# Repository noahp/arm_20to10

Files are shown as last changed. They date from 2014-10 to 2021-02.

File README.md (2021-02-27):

arm_20to10
=====
20-pin to 10-pin ARM JTAG/SWD adapter, with toggle-able 3.3v LDO 
to power the target (jlink can output 5.0v on pin 19 of the arm 
20-pin connector).

pcb render
=====
front. . . . . .  back

assembly render
=====
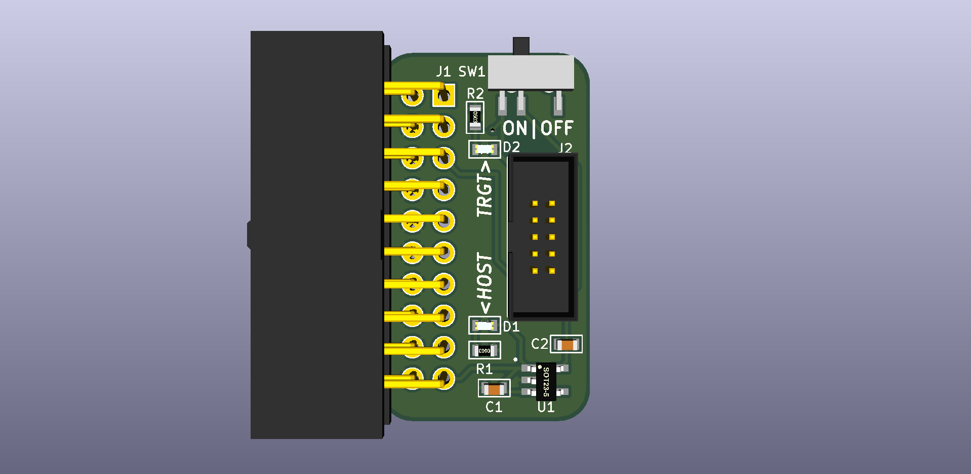
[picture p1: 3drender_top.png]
top

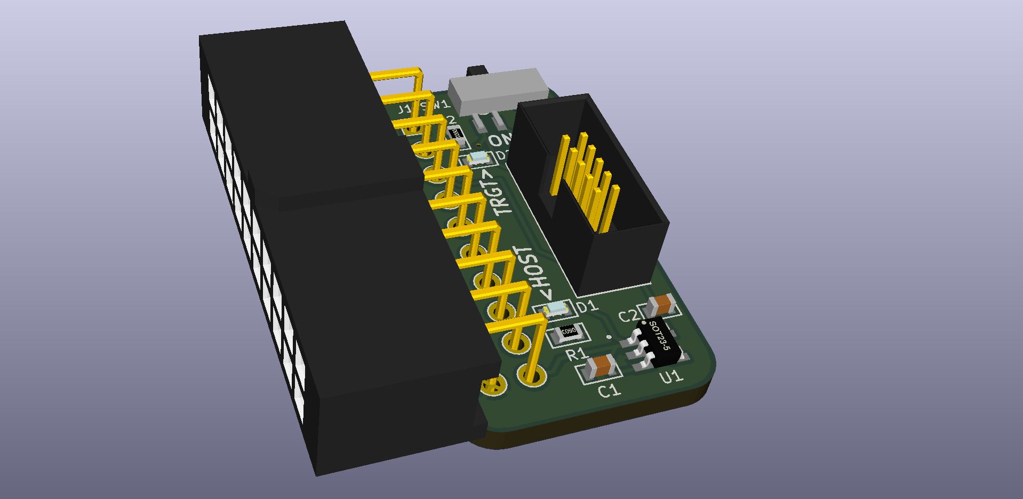
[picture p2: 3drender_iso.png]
iso


assembled unit
=====
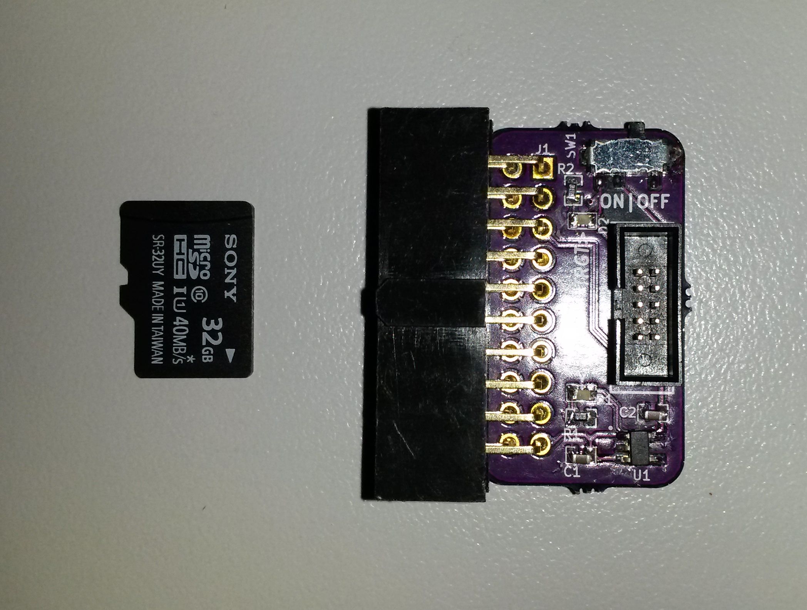
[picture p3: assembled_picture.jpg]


parts
=====
10 pin through hole male connector
-----
[digikey](http://www.digikey.com/product-detail/en/20021111-00010T4LF/609-3712-ND/2209072)  
[mouser](http://www.mouser.com/ProductDetail/FCI/20021111-00010T4LF/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)  
[ebay](http://www.ebay.com/itm/12-pcs-Gold-Plated-1-27mm-2x40-80pin-Breakable-Pin-Header-Male-Double-Row-Strip-/370935487630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)  
  
[shrouded, digikey](http://www.digikey.com/product-detail/en/3220-10-0100-00/1175-1627-ND/3883661)  

20 pin through hole female connector
-----
[digikey](http://www.digikey.com/product-detail/en/SFH11-PBPC-D10-ST-BK/S9197-ND/1990090)  
[ebay](http://www.ebay.com/itm/20-Pcs-2x10-Double-Row-20-Pins-PCB-Female-Header-2-54mm-/400316132430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)  
[digkey right angle](http://www.digikey.com/product-detail/en/SFH11-PBPC-D10-RA-BK/S9205-ND/1990098)  

3.3v ldo
-----
[mouser- skyworks sot23-5](http://www.mouser.com/ProductDetail/Skyworks-Solutions-Inc/AAT3223IGU-33-T1/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)  
[mouser- TI sot23-5](http://www.mouser.com/ProductDetail/Texas-Instruments/LP5907MFX-33-NOPB/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)  
[digikey- TI sot23-5](http://www.digikey.com/product-detail/en/TLV70233DBVR/296-32415-1-ND/3505572)  
[digikey- Micrel sot23-5 300mA](http://www.digikey.com/product-detail/en/MIC5504-3.3YM5%20TR/576-4764-1-ND/4864028)  

beefier ldo
----
[mouser- ON](http://www.mouser.com/ProductDetail/ON-Semiconductor/NCP1117LPST33T3G/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)  
[mouser- diodes](http://www.mouser.com/ProductDetail/Diodes-Incorporated/AP1117IE33G-13/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)  

slide switch
-----
[mouser- C&K](http://www.mouser.com/ProductDetail/CK-Components/PCM12SMTR/?qs=sGAEpiMZZMsqIr59i2oRcvc9UQrBbcoBkFYgnQFYwWU%3d)  
[digikey- Copal](http://www.digikey.com/product-detail/en/CUS-12TB/563-1102-1-ND/1124231)  
[mouser- ALPS](http://www.mouser.com/ProductDetail/ALPS/SSSS810701/?qs=sGAEpiMZZMtHXLepoqNyVe%252bcQMRoBF1BAzyvwoNmgBo%3d)

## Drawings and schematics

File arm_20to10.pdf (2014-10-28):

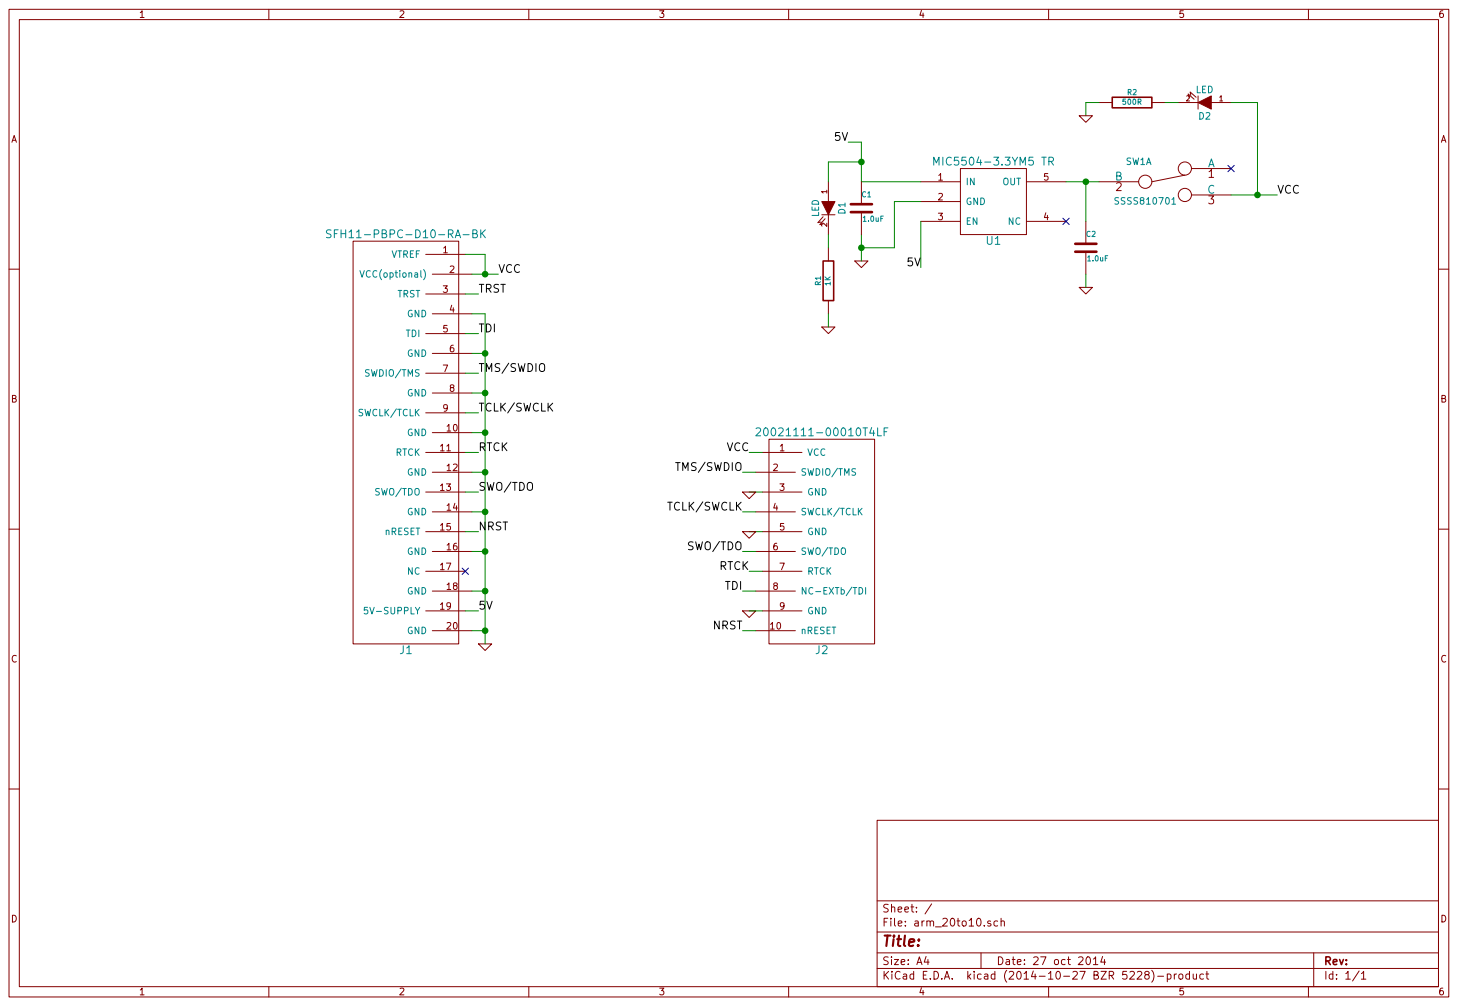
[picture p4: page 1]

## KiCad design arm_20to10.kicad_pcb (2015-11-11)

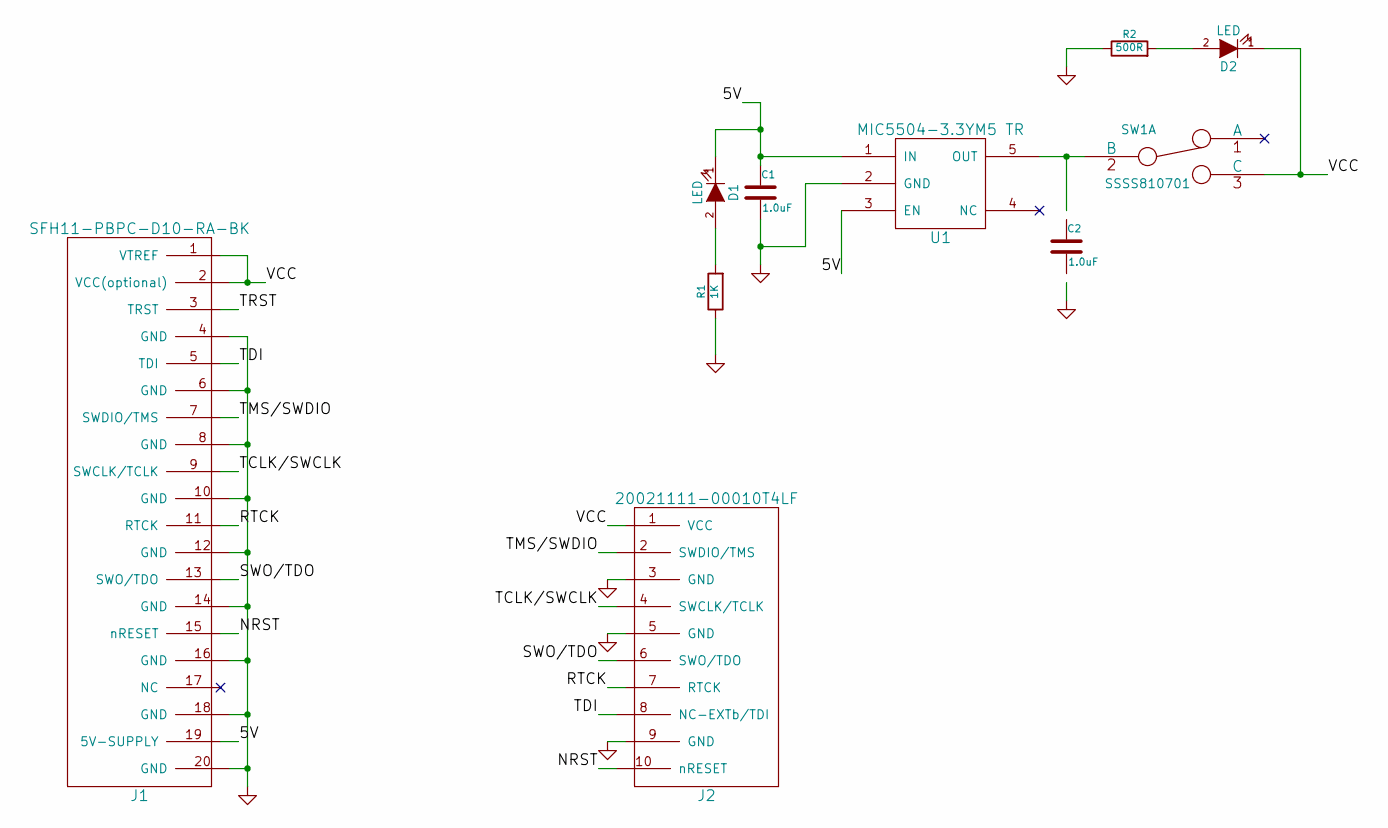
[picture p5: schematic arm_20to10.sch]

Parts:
C1, C2: 1.0uF; SMD_0603_C
D1, D2: LED; SMD_0603_LED
J1: SFH11-PBPC-D10-RA-BK; ARM_20_PIN_TH_RIGHTANGLE
J2: 20021111-00010T4LF; ARM_10_PIN
R1: 1K; SMD_0603_R
R2: 500R; SMD_0603_R
SW1: SSSS810701; SWITCH_SLIDE_SSSS810701
U1: MIC5504-3.3YM5 TR; sot23-5_noah

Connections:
/5V: C1.1, D1.1 (K), J1.19 (5V-SUPPLY), U1.1 (IN), U1.3 (EN)
/NRST: J1.15 (nRESET), J2.10 (nRESET)
/RTCK: J1.11 (RTCK), J2.7 (RTCK)
/SWO/TDO: J1.13 (SWO/TDO), J2.6 (SWO/TDO)
/TCLK/SWCLK: J1.9 (SWCLK/TCLK), J2.4 (SWCLK/TCLK)
/TDI: J1.5 (TDI), J2.8 (NC-EXTb/TDI)
/TMS/SWDIO: J1.7 (SWDIO/TMS), J2.2 (SWDIO/TMS)
/TRST: J1.3 (TRST)
/VCC: D2.1 (K), J1.1 (VTREF), J1.2 (VCC(optional)), J2.1 (VCC), SW1.3 (C)
GND: C1.2, J1.4 (GND), J1.6 (GND), J1.8 (GND), J1.10 (GND), J1.12 (GND), J1.14 (GND), J1.16 (GND), J1.18 (GND), J1.20 (GND), J2.3 (GND), J2.5 (GND), J2.9 (GND), R1.1, R2.1, U1.2 (GND)
unnamed: D1.2 (A), R1.2
unnamed: D2.2 (A), R2.2
unnamed: SW1.2 (B), U1.5 (OUT)

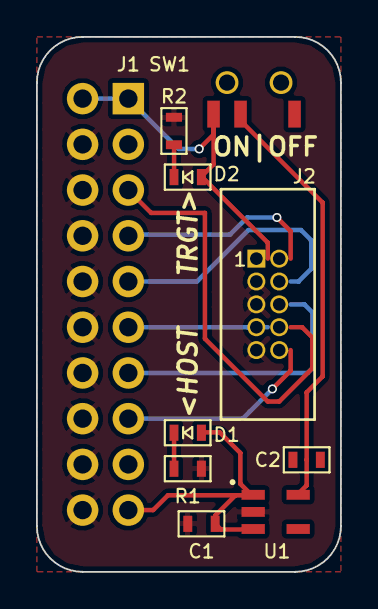
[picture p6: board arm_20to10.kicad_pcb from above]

Board: 2 copper layers, 16.9 x 29.7 mm, 10 parts (0 on the bottom side), 12 nets.

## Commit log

2014-01-29 - add schematic and project file
    [arm_20to10.sch]
2014-01-30 - save
    [arm_20to10.sch]
2014-01-30 - start layout
    [arm_20to10.kicad_pcb, arm_20to10.sch]
2014-01-30 - add gerbers, finish layout
    [arm_20to10-B_Cu.gbl, arm_20to10-B_Mask.gbs, arm_20to10-B_SilkS.gbo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]
2014-01-31 - layout done. add gnd next to vcc test point.
    [arm_20to10.kicad_pcb, arm_20to10.sch]
2014-01-31 - generate gerbers
    [arm_20to10-B_Cu.gbl, arm_20to10-B_Mask.gbs, arm_20to10-B_SilkS.gbo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]
2014-02-13 - add 3.3v supply option
    [arm_20to10.sch]
2014-02-20 - add comp. associations for ldo + switch
    [arm_20to10.sch]
2014-02-20 - new layout w/ ldo + switch
    [arm_20to10-B_Cu.gbl, arm_20to10-B_Mask.gbs, arm_20to10-B_SilkS.gbo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]
2014-03-08 - add power indicator leds
    [arm_20to10.sch]
2014-03-08 - set some comp values
    [arm_20to10.sch]
2014-03-08 - re layout with leds
    [arm_20to10-B_Cu.gbl, arm_20to10-B_Mask.gbs, arm_20to10-B_SilkS.gbo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]
2014-04-23 - redo with 0402 resistors
    [arm_20to10-B_Cu.gbl, arm_20to10-B_Mask.gbs, arm_20to10-B_SilkS.gbo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]
2014-06-18 - change url ref, replot gerbers, fresh pcb renders
    [arm_20to10-B_Cu.gbl, arm_20to10-B_Mask.gbs, arm_20to10-B_SilkS.gbo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]
2014-07-18 - fix thermals on the 0402's... footprints still too small
    [arm_20to10-B_Cu.gbl, arm_20to10-B_Mask.gbs, arm_20to10-B_SilkS.gbo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]
2014-10-27 - start reworking board with new 20 pin header
    [arm_20to10.kicad_pcb, arm_20to10.sch]
2014-10-28 - outline and pours done
    [arm_20to10.kicad_pcb]
2014-10-28 - select noah's kicadlib in new library mgr
2014-10-28 - pcb done.
    [arm_20to10.kicad_pcb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]
2014-10-30 - generate new gerbs.
    [arm_20to10.kicad_pcb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]
2014-12-02 - update with new arm 20 pin TH pinout - rework silks a bit to be more readable - add silk url to the back
    [arm_20to10-B_Cu.gbl, arm_20to10-B_Mask.gbs, arm_20to10-B_SilkS.gbo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]
2014-12-02 - update pcb renders
2015-10-29 add image of assembled board
2015-11-05 try to add some models
    [arm_20to10.kicad_pcb, arm_20to10.sch]
2015-11-06 arm 10 pin th model!
    [arm_20to10.kicad_pcb]
2015-11-06 add slide sw model
    [arm_20to10.kicad_pcb]
2015-11-08 update 3d symbols, relative paths!
    [arm_20to10.kicad_pcb]
2015-11-08 update arm 20 pin right angle, all models done
    [arm_20to10.kicad_pcb]
2015-11-11 generate new gerbers
    [arm_20to10-B_Cu.gbl, arm_20to10-B_Mask.gbs, arm_20to10-B_SilkS.gbo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]
2015-11-11 update pcb renders
2021-02-27 Add not about 3.3v ldo
